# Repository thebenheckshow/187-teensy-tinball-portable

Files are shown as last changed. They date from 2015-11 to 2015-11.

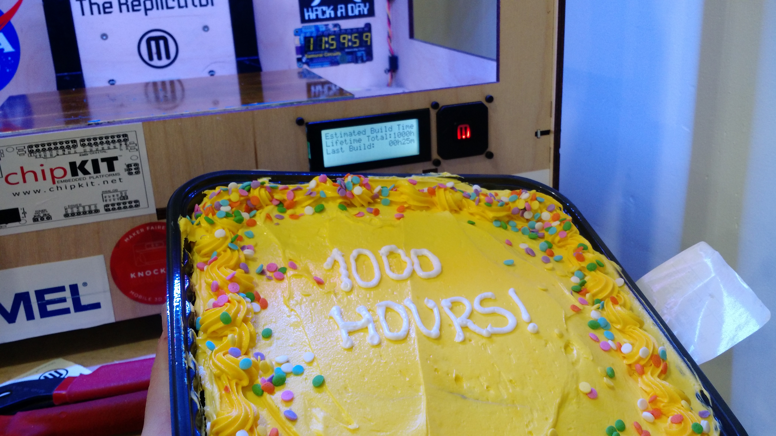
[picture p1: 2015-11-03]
pics/IMG_20150506_124653176.jpg

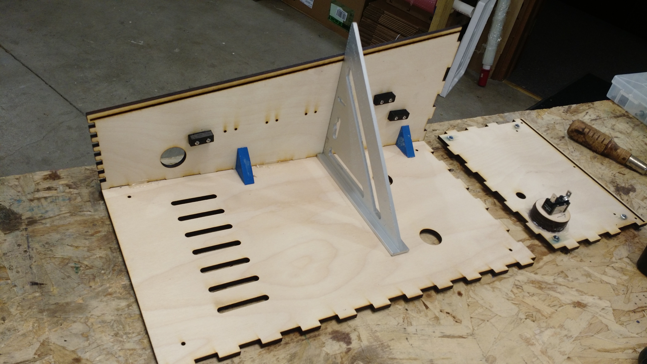
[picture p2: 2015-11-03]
pics/IMG_20150509_173802297.jpg

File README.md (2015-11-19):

# 187-teensy-tinball-portable

In this episode series Ben creates a mini pinball machine portable for this years Freescale Technology Forum in Austin,Texas. The pinball machine be half scale, will run off of the Teensy 3.1 and will have electronic music and scoring.

Visit the Ben Heck Community and Suggest a Build: http://www.element14.com/tbhs

Part 1: http://www.element14.com/community/docs/DOC-76788/l/episode-187-ben-heck-s-teensy-pinball-portable-part-1-episode

Part 2: http://www.element14.com/community/docs/DOC-77092/l/episode-189-ben-hecks-teensy-pinball-portable-part-2-episode

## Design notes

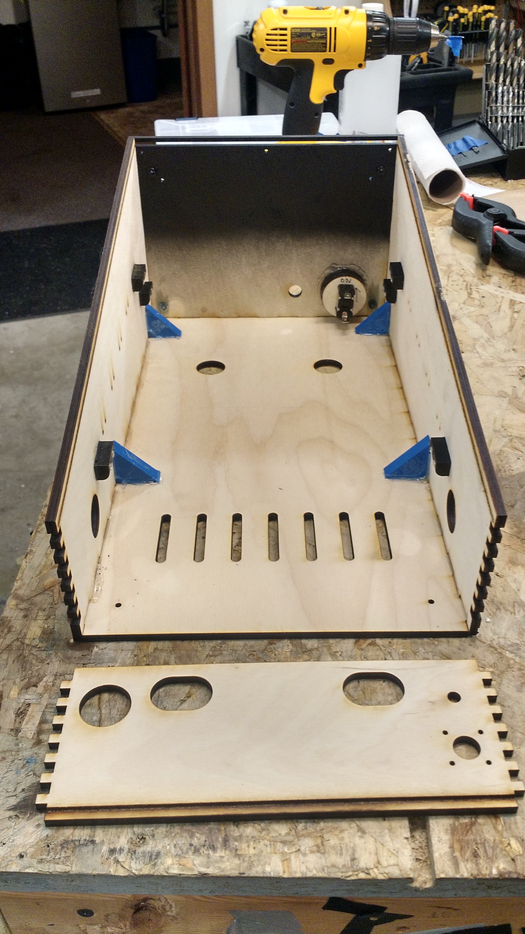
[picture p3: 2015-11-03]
pics/IMG_20150509_180624918_HDR.jpg

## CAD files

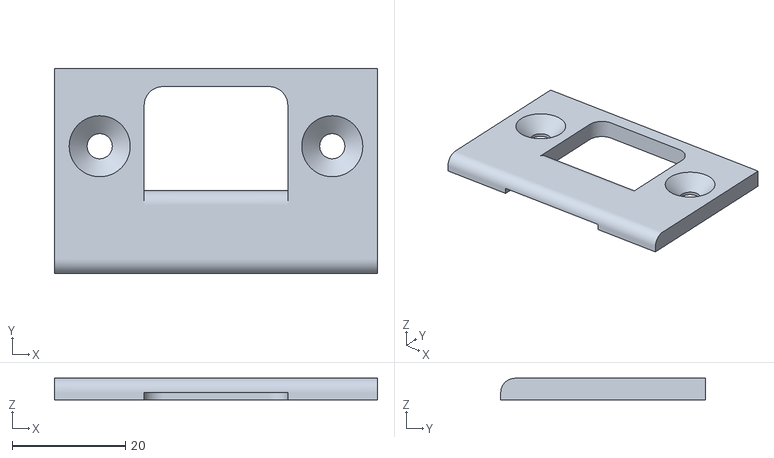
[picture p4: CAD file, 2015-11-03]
3D parts/STL/Door Fixer.stl
57.1 x 36.2 x 3.81

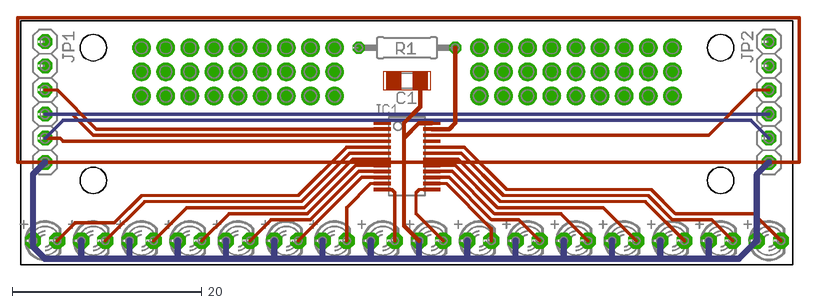
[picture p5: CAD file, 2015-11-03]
parts/LED Driver Boards/led_driver.dxf
82.5 x 26.2

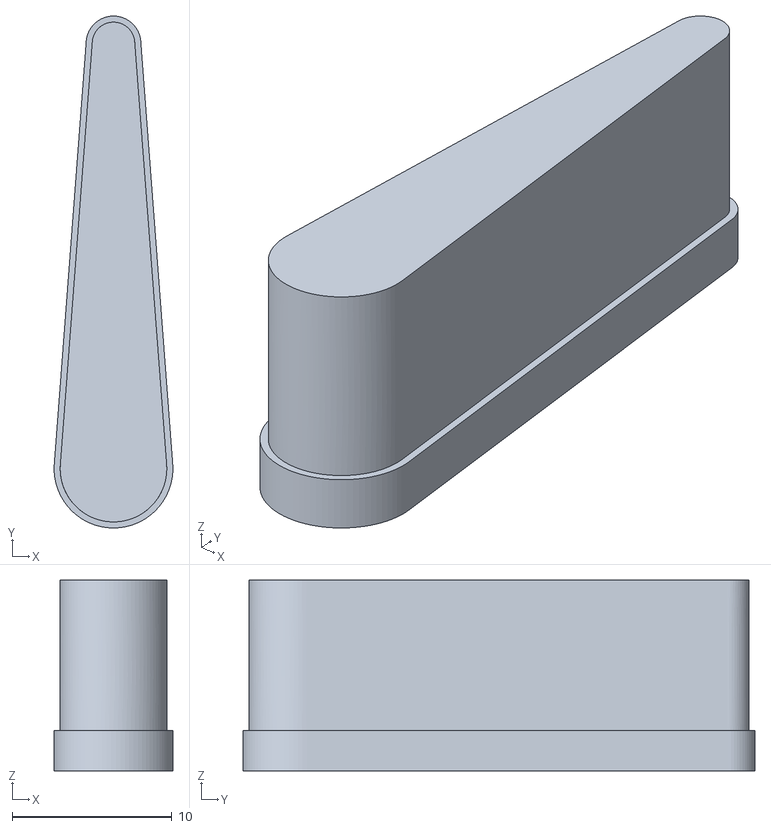
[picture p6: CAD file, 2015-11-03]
STL Test/flipper_shape.stl
7.43 x 32.0 x 11.9

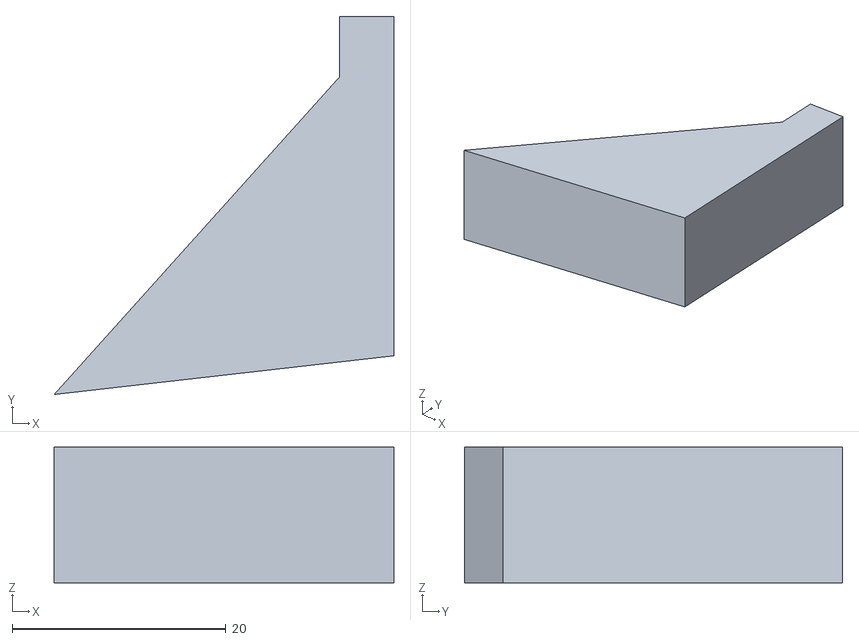
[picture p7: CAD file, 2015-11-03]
3D parts/STL/6 point 5 Triangle.stl
31.8 x 35.4 x 12.7

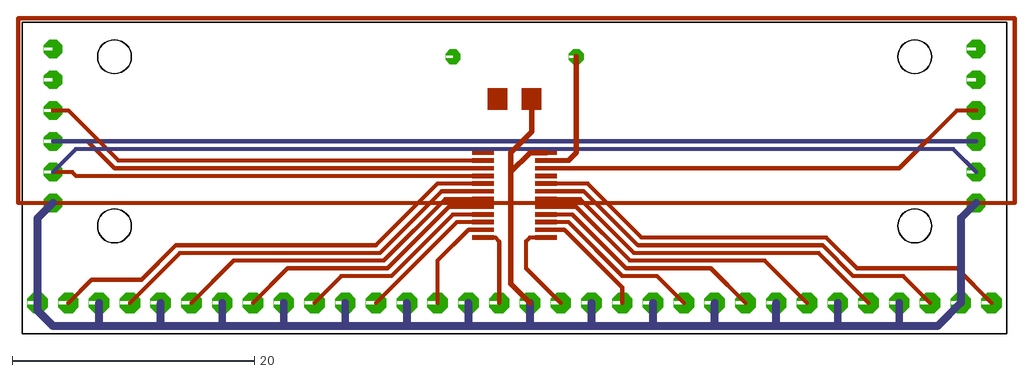
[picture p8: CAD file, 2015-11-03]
parts/LED Driver Boards/led_driver2.dxf
82.5 x 26.2

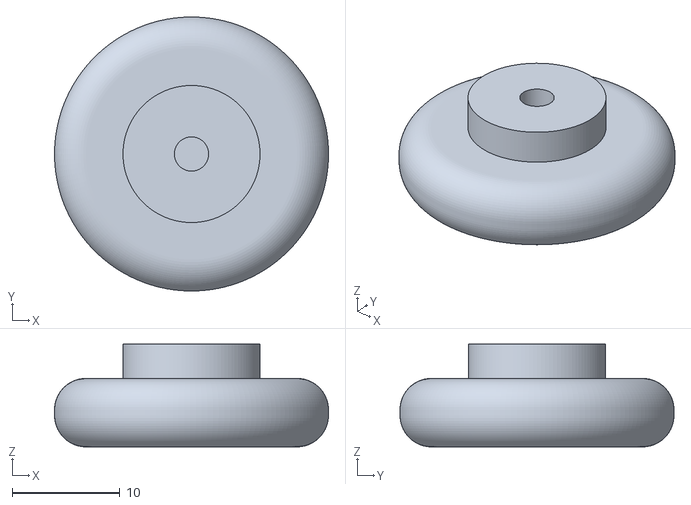
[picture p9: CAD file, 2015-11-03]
3D parts/STL/Plunger Handle.stl
25.4 x 25.4 x 9.53

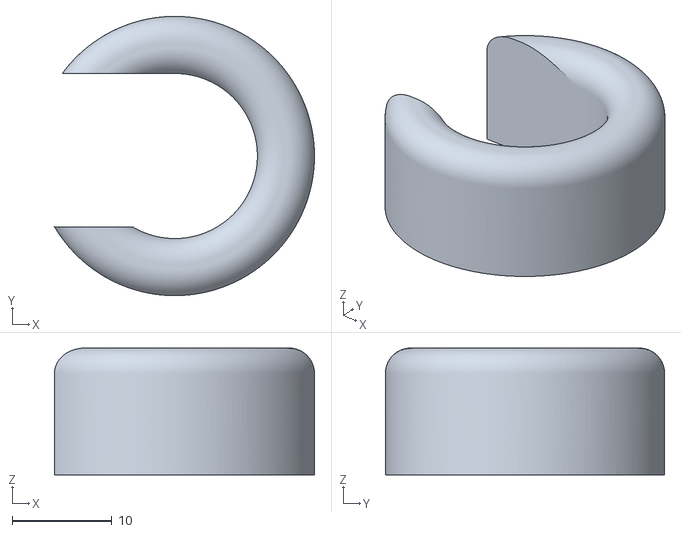
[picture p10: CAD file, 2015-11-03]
3D parts/STL/Left Ramp End.stl
26.0 x 27.9 x 12.7

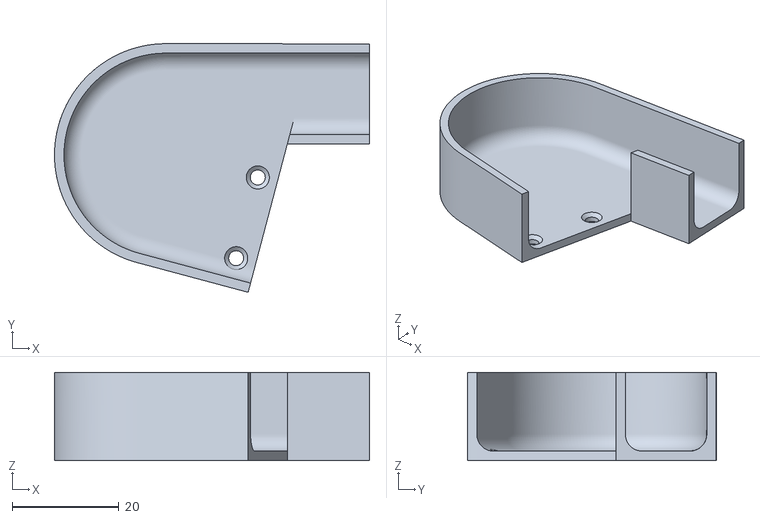
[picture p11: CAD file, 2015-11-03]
3D parts/STL/Right Ramp Loop 2.stl
58.9 x 46.5 x 16.5

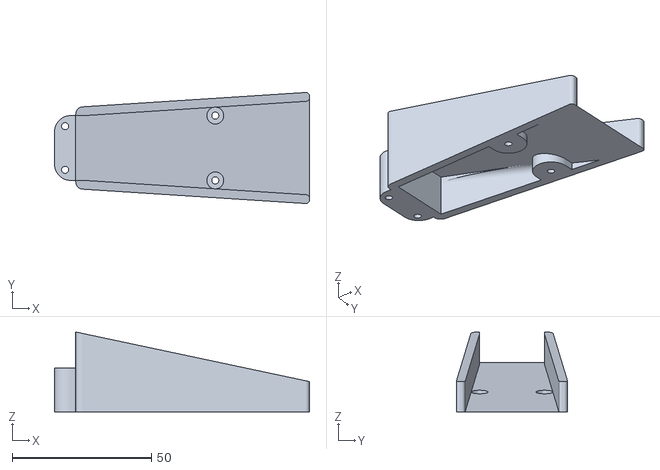
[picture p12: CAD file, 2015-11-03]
3D parts/STL/ramp.stl
91.4 x 39.8 x 28.7

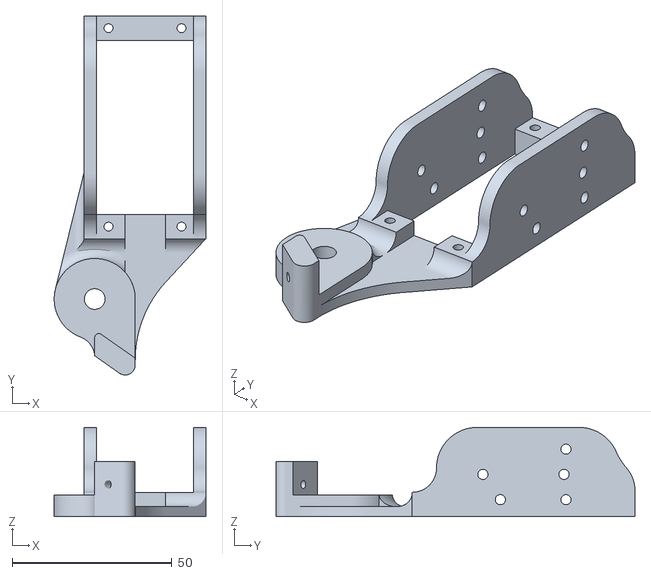
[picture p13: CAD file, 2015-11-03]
3D parts/STL/New Flipper Frame.stl
47.5 x 112.5 x 27.9

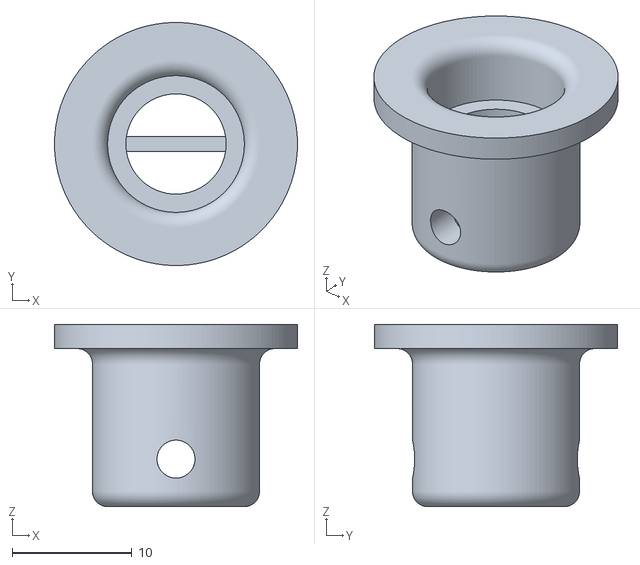
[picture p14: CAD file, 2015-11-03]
3D parts/STL/Stopper Cap.stl
20.3 x 20.3 x 15.2

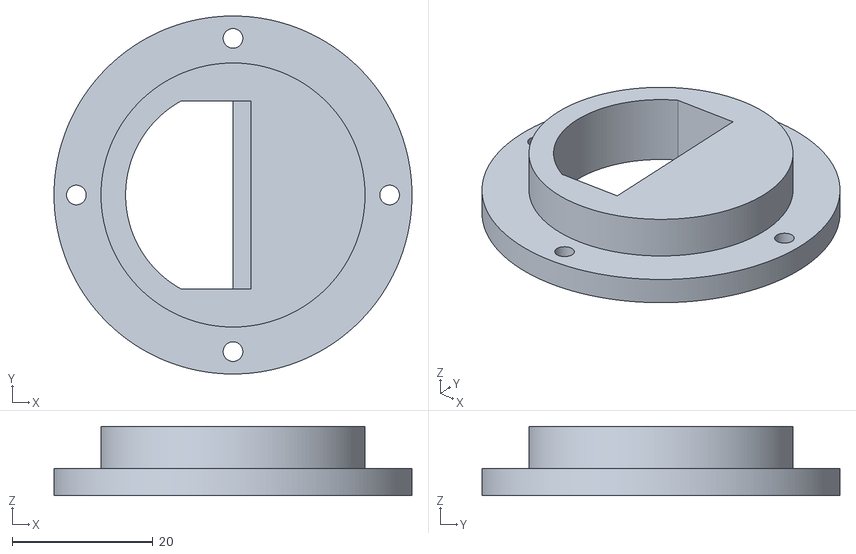
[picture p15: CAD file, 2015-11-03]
3D parts/STL/Target Base.stl
50.8 x 50.8 x 9.81

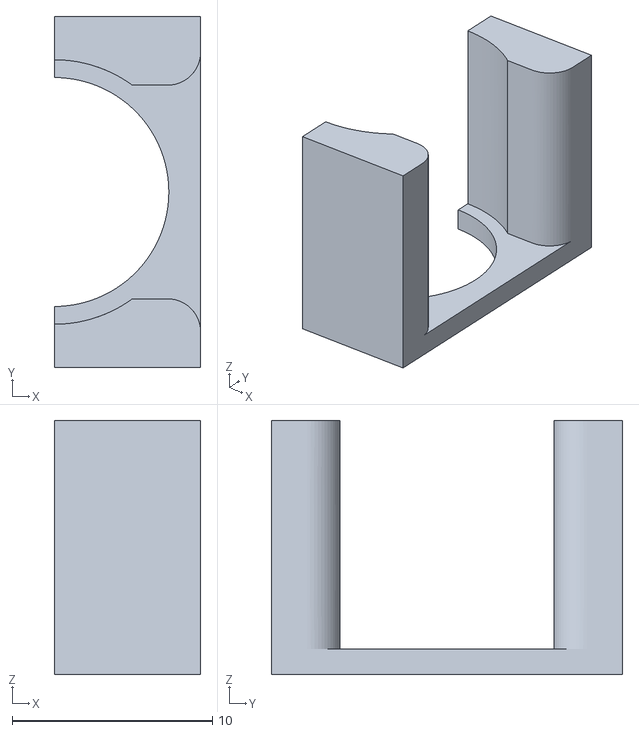
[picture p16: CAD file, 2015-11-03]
3D parts/STL/Ball Launch Holder.stl
7.30 x 17.5 x 12.7

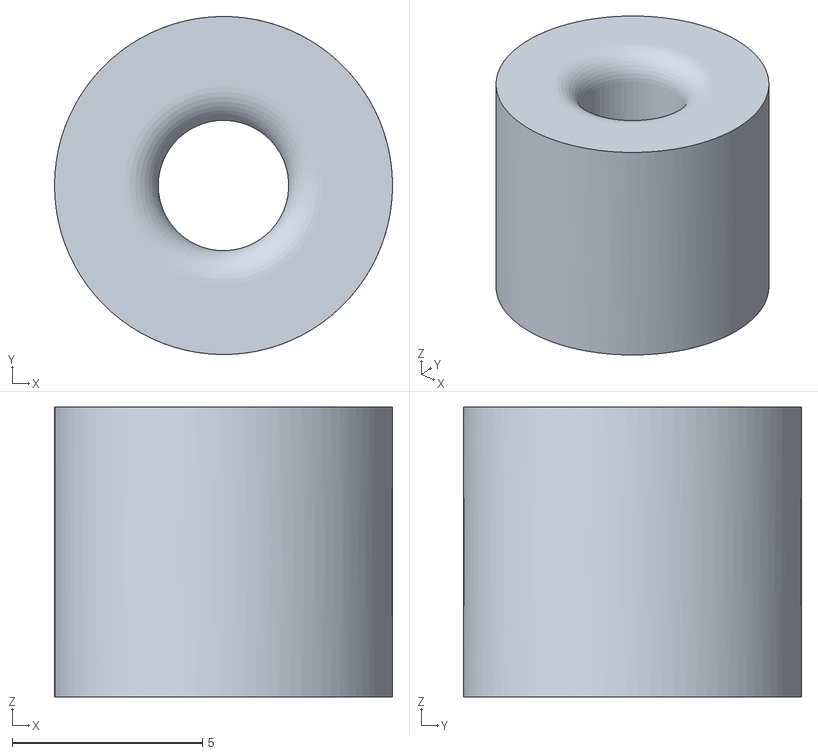
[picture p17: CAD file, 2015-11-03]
3D parts/STL/Spacer point 3.stl
8.89 x 8.89 x 7.62

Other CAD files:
3D parts/STL/Drop Target.stl
3D parts/STL/Opto Mount 2.stl
3D parts/STL/Shooter Tip.stl
3D parts/STL/Large LED holder.stl
3D parts/STL/Flipper Bat.stl
3D parts/STL/Foot.stl
3D parts/STL/Habitrail End 2.stl
3D parts/STL/Habitrail End.stl
3D parts/STL/Habitrail Top.stl
3D parts/STL/Hole Temp.stl
3D parts/STL/Knob.stl
3D parts/STL/LED holder.stl
3D parts/STL/LED screw left.stl
3D parts/STL/LED screw right.stl
3D parts/STL/Launch Ramp.stl
3D parts/STL/Left Ramp Loop.stl
3D parts/STL/New Flipper Clamp Flipped.stl
3D parts/STL/New Flipper Clamp.stl
3D parts/STL/New Flipper Frame Flipped.stl
3D parts/STL/New Flipper Linkage.stl
3D parts/STL/Opto Mount.stl
3D parts/STL/Plastic Spacer 200 mils THEEEN.stl
3D parts/STL/Plastic Spacer 200 mils.stl
3D parts/STL/Right Ramp End.stl
3D parts/STL/Right Ramp Loop.stl
3D parts/STL/Shooter Rod Mount 2.stl
3D parts/STL/Shooter Rod Mount.stl
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

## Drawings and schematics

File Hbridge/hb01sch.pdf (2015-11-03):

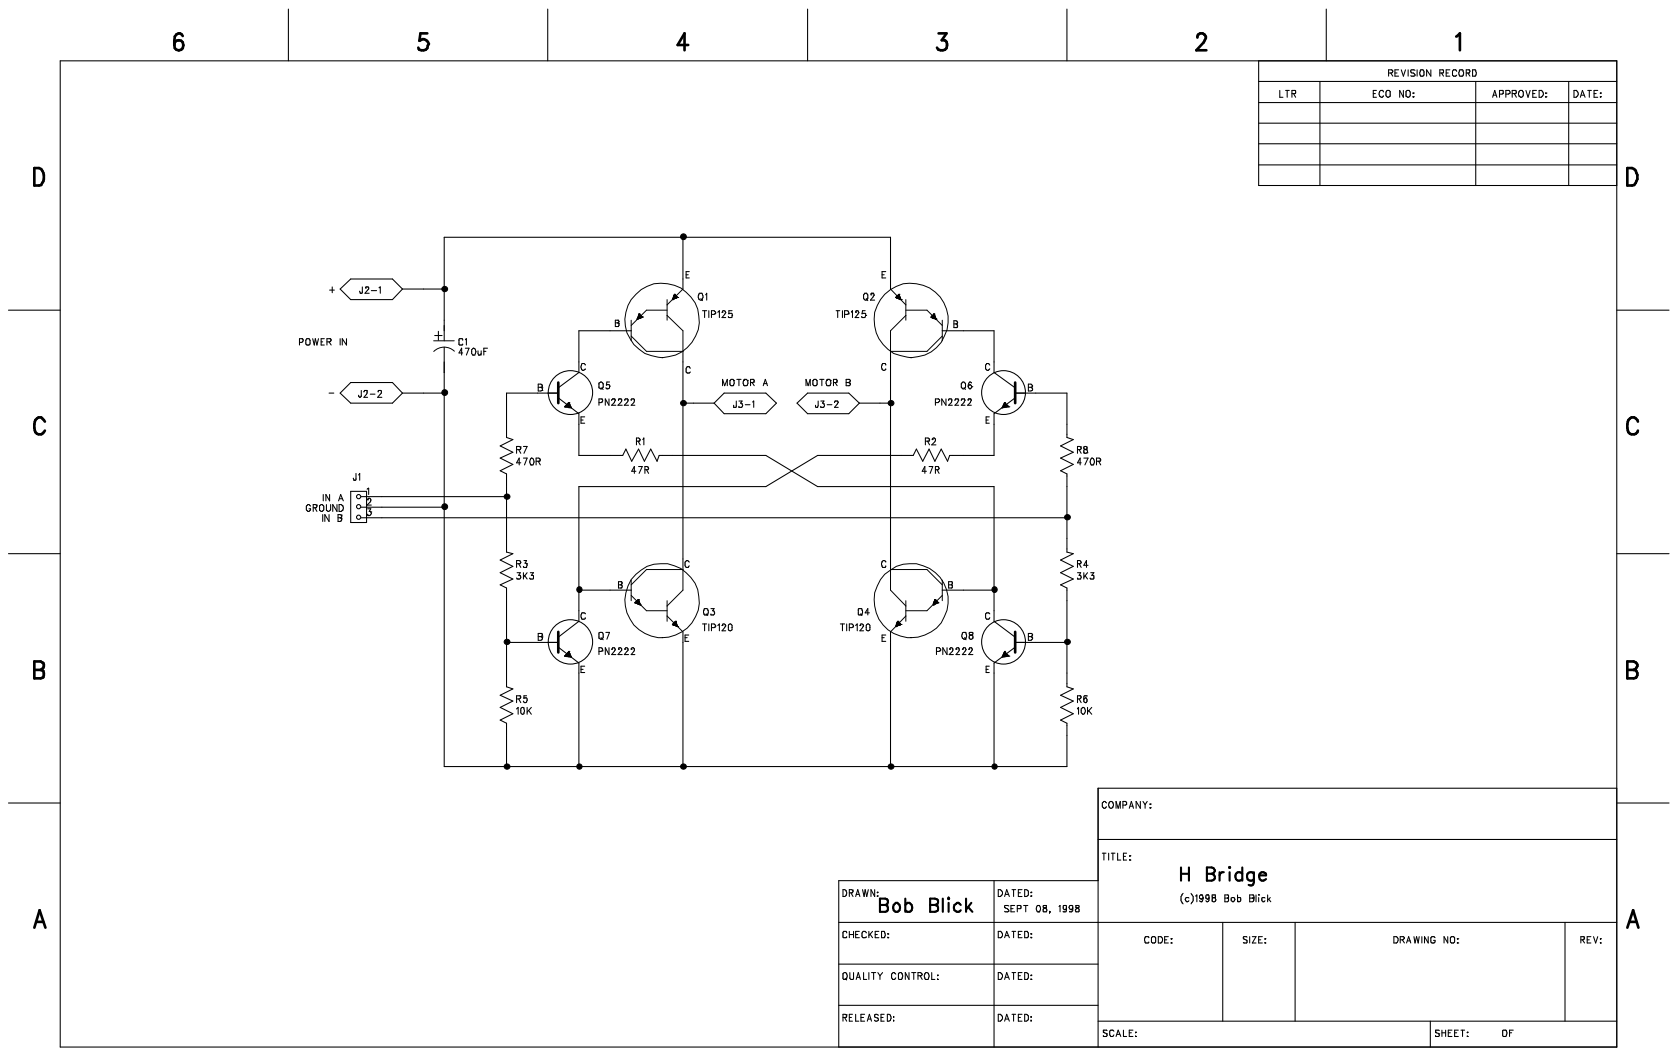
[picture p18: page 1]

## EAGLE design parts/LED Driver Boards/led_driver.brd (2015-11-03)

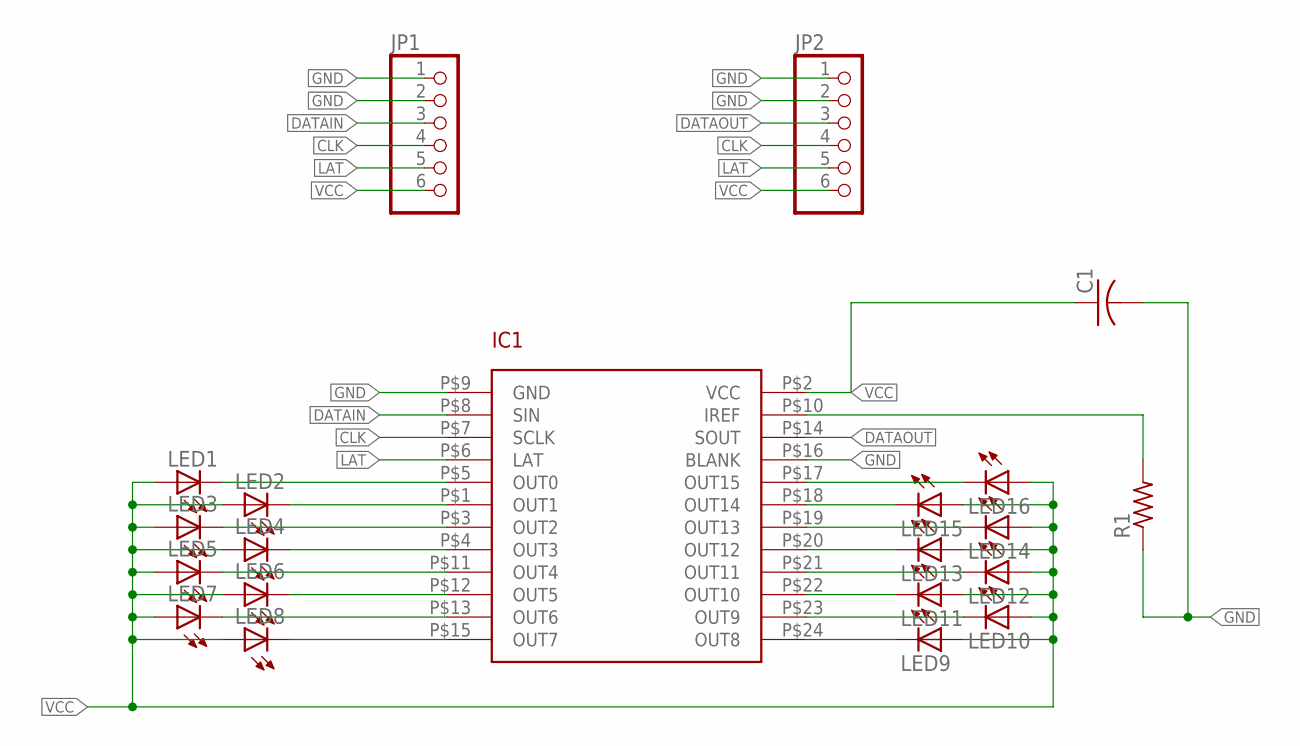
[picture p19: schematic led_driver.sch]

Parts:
C1: C-USC1206; C1206
IC1: TLC59282; SSOP-24
JP1, JP2: PINHD-1X6; 1X06
LED1, LED2, LED3, LED4, LED5, LED6, LED7, LED8, LED9, LED10, LED11, LED12, LED13, LED14, LED15, LED16: LED3MM
R1: R-US_0207/10; 0207/10

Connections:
CLK: IC1.P$7 (SCLK), JP1.4, JP2.4
DATAIN: IC1.P$8 (SIN), JP1.3
DATAOUT: IC1.P$14 (SOUT), JP2.3
GND: C1.2, IC1.P$9 (GND), IC1.P$16 (BLANK), JP1.1, JP1.2, JP2.1, JP2.2, R1.1
LAT: IC1.P$6 (LAT), JP1.5, JP2.5
unnamed: IC1.P$5 (OUT0), LED1.K (C)
unnamed: IC1.P$1 (OUT1), LED2.K (C)
unnamed: IC1.P$3 (OUT2), LED3.K (C)
unnamed: IC1.P$4 (OUT3), LED4.K (C)
unnamed: IC1.P$11 (OUT4), LED5.K (C)
unnamed: IC1.P$12 (OUT5), LED6.K (C)
unnamed: IC1.P$13 (OUT6), LED7.K (C)
unnamed: IC1.P$15 (OUT7), LED8.K (C)
unnamed: IC1.P$17 (OUT15), LED16.K (C)
unnamed: IC1.P$18 (OUT14), LED15.K (C)
unnamed: IC1.P$19 (OUT13), LED14.K (C)
unnamed: IC1.P$20 (OUT12), LED13.K (C)
unnamed: IC1.P$21 (OUT11), LED12.K (C)
unnamed: IC1.P$22 (OUT10), LED11.K (C)
unnamed: IC1.P$23 (OUT9), LED10.K (C)
unnamed: IC1.P$24 (OUT8), LED9.K (C)
unnamed: IC1.P$10 (IREF), R1.2
VCC: C1.1, IC1.P$2 (VCC), JP1.6, JP2.6, LED1.A, LED2.A, LED3.A, LED4.A, LED5.A, LED6.A, LED7.A, LED8.A, LED9.A, LED10.A, LED11.A, LED12.A, LED13.A, LED14.A, LED15.A, LED16.A

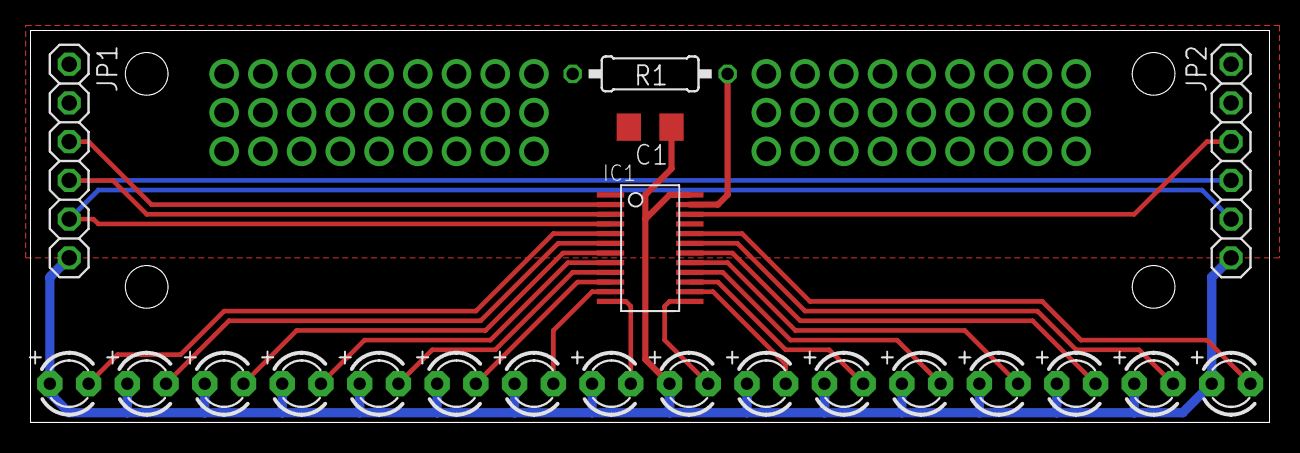
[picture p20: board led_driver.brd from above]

Board: 4 copper layers, 81.3 x 25.7 mm, 21 parts (0 on the bottom side), 23 nets.

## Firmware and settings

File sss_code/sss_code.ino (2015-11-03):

#include "pinball.h"
#include "kinetis.h"
#include "pins_arduino.h"
#include <EEPROM.h>

#include <Audio.h>
#include <Wire.h>
#include <SPI.h>
#include <SD.h>

volatile byte lamp[32];
volatile byte solenoid[16];
volatile unsigned short LEDcommand = 0;
volatile unsigned char whichDigit = 0;												//Which digit we're sending to the MAX7221
volatile char scoreString[7] = {0, 0, 0, 0, 0, 0, 0};								//Used to build the digits to go on the LED
volatile char tempString[7] = {0, 0, 0, 0, 0, 0, 0};								//Used to make temp Score String to right-align value
volatile unsigned short digitData = 0;												//Used to build data going to the MAX7221	
volatile unsigned short cabTemp = 0;												//Used to collect the cabinet switch data
byte LEDglow = 0;
byte LEDglowDir = 0;

unsigned long currentMillis = 0;
char sfxFilename[8] = {'x', 'x', 'x', '.', 'W', 'A', 'V', 0};
byte priority[2];
byte musicPlaying = 0;
char currentMusic[3] = {'x', 'x', 'x'};

int timerX = 0;

AudioPlaySdWav           playWav[2];					//Set up two channel stereo audio mixed into a stereo signal
AudioMixer4              mixer2;
AudioMixer4              mixer1;
AudioOutputI2S           i2s1;
AudioConnection          patchCord1(playWav[0], 0, mixer1, 0);
AudioConnection          patchCord2(playWav[0], 1, mixer2, 0);
AudioConnection          patchCord3(playWav[1], 0, mixer1, 1);
AudioConnection          patchCord4(playWav[1], 1, mixer2, 1);
AudioConnection          patchCord5(mixer2, 0, i2s1, 1);
AudioConnection          patchCord6(mixer1, 0, i2s1, 0);
AudioControlSGTL5000     sgtl5000_1;

IntervalTimer pollIOtimer;								//Set up a timer

void setup() {                

    Serial.begin(9600);
	
	pinMode(shiftClock, OUTPUT);						//Master clock  
	pinMode(shiftLatch, OUTPUT); 						//Master latch
	pinMode(shiftLamp0, OUTPUT); 						//LED driver 0 (lamps 0-15)
	pinMode(shiftLamp1, OUTPUT); 						//LED driver 1(lamps 16-31)
	pinMode(shiftSol, OUTPUT); 							//Solenoid drivers 0-15
	pinMode(shiftLED, OUTPUT); 							//MAX7221 7 segment LED driver
	pinMode(shiftInput, INPUT);							//Shift register switch input line
	
	pollIOtimer.begin(pollIO, 4000);					//Do the PollIO routine 250Hz (or every 4000 microseconds)

	AudioMemory(32);									//Twice of the max, which seems to be 6

	sgtl5000_1.enable();
	sgtl5000_1.volume(1);

	SPI.setMOSI(7);
	SPI.setSCK(14);
	
	if (!(SD.begin(10))) {	
		while (1) {
		  Serial.println("Unable to access the SD card");	// stop here, but print a message repetitively 
		  delay(500);
		}
	}
	else {
		Serial.println("Connected to SD card!");
		delay(500);      
	}


	resetLED();											//Reset the display
	
}

void loop() {

	machineReset();

	while (run == 0) {
	
		Serial.println(cabinet, BIN);	
	
		//Attract Mode Shit
	
		if (cabinet & startButton) {

			if (cabinet & drain) {	//Ball must be in drain to start!
				startButtonTimer = 250;
				run = 1;											//Advance state if START pressed
			}
			else {
				scoreString[0] = digitMaker[17]; 	//N
				scoreString[1] = digitMaker[0];		//0	
				scoreString[2] = 0; 				//space	
				scoreString[3] = digitMaker[10]; 	//B
				scoreString[4] = digitMaker[11];	//A		
				scoreString[5] = digitMaker[12];	//L
				scoreString[6] = digitMaker[12];	//L	
				displayCycle = 0;					//So we'll see message
			}
		}

		displayCycle += 1;

		switch(displayCycle) {
			
			case 1500:
				blankLED();
				scoreString[0] = digitMaker[15]; 	//H
				scoreString[1] = digitMaker[1];		//1		
				scoreString[2] = digitMaker[16];	//G
				scoreString[3] = digitMaker[15];	//H
			break;
			case 3000:
				makeScore(highScore);	//Show score, and repeat	
				displayCycle = 0;
			break;		
		}
		
		houseKeeping();
	
	}

	startGame();
	
	while (ball < 4) {
	
		gameLoop();
	}
	
	gameOver();
	
}

void gameLoop() {

	timers();
	
	switchCheck();
	
	houseKeeping();							//1 ms cycle lock and Music Loop check performed in this function

}

void timers() {

	if (motorState) {						//Motor is supposed to be doing something?
		doMotor();							//Go do it
	}
	
	if (leftLoopTimer) {		
		leftLoopTimer -= 1;	
	}	
	
	if (leftRampTimer) {		
		leftRampTimer -= 1;	
	}	
	
	if (rightRampTimer) {		
		rightRampTimer -= 1;	
	}
	
	if (rightLoopTimer) {		
		rightLoopTimer -= 1;	
	}	

	if (startButtonTimer and (cabinet & startButton) == 0) {	
		startButtonTimer -= 1;		
	}
	
	displayCycle += 1;

	switch(displayCycle) {
		
		case 2000:
		if (numPlayers > 1) {
			blankLED();
			scoreString[0] = digitMaker[13];		//P
			scoreString[1] = digitMaker[12];		//L	
			scoreString[2] = digitMaker[11];		//A				
			scoreString[3] = digitMaker[14];		//Y skip one space...
			scoreString[5] = digitMaker[player];	//Player #			
		}		
		else {
			displayCycle = 2999;		//If only 1 player, don't show player # just skip to score
		}
		break;
		case 3000:		
			blankLED();
			scoreString[1] = digitMaker[10]; 	//B
			scoreString[2] = digitMaker[11];	//A		
			scoreString[3] = digitMaker[12];	//L
			scoreString[4] = digitMaker[12];	//L skip one space then	
			scoreString[6] = digitMaker[ball];	//Ball #

		break;	
		case 4000:
			makeScore(playerScore[player]);	//Show score, and repeat	
			displayCycle = 1000;
		break;		
	}
	
}

void switchCheck() {

	//FLIPPERS GO HERE!

	flippers();
	
	if ((cabinet & startButton) == 1 and startButtonTimer == 0) {	
		startButtonTimer = 250;
		if (numPlayers < 4 and ball == 1) {						//Can only add players on Ball 1
			numPlayers += 1;			//Increment player #		
			playSFX(0, 'S', 'B', '0' + numPlayers, 255);		//Add player 2-4		
		}	
	}

	if ((cabinet & drain) and drainState == 0) {
	
		drainBall();
	
	}

	if ((cabinet & leftLoop) and leftLoopTimer == 0 and rightLoopTimer == 0) {
		leftLoopTimer = loopDebounce;
	
		if (mode == 0) {					//No mode?
		
			modePrompt(2);					//Play generic sound for orbits, with START MODE prompts
			
			leftOrbitCount[player] += 1;
			
			if (leftOrbitCount[player] > 3) {
				leftOrbitCount[player] = 0;
				addScore(2000);
			}
			else {
				addScore(1000);
			}
			
			playerLights();
	
		}
		else {								//Some mode is active...
		
			if (mode == 1) {				//Hubble mode? correct shot
			
				hubbleProgress[player] += 1;
				playSFX(0, 'A', 'A' + hubbleProgress[player], '1' + random(3), 255);	//Progress dialog

				if (hubbleProgress[player] == 3) {				
					addScore(50000);
					winMode();
				}
				else {
					addScore(5000);
				}
				playerLights();
				
			}
			else {
			
				modePrompt(2);				//Play generic sound for orbits, with MODE PROGRESS prompts
				addScore(2000);	
			}
			
		}

	}
	
	if ((cabinet & leftRamp) and leftRampTimer == 0) {
		leftRampTimer = rampDebounce;
				
		if (mode == 0) {					//No mode?
		
			modePrompt(1);					//Play generic sound for orbits, with START MODE prompts
			leftRampCount[player] += 1;
			
			if (leftRampCount[player] > 3) {
				leftRampCount[player] = 0;
				addScore(4000);
			}
			else {
				addScore(2000);
			}
			
			playerLights();
		}
		else {								//Some mode is active...
		
			if (mode == 2) {				//ISS mode? correct shot
			
				issProgress[player] += 1;
				playSFX(0, 'B', 'A' + issProgress[player], '1' + random(3), 255);	//Progress dialog

				if (issProgress[player] == 3) {				
					addScore(50000);
					winMode();
				}
				else {
					addScore(5000);
				}
				playerLights();	
				
			}
			else {
			
				modePrompt(1);				//Play generic sound for orbits, with MODE PROGRESS prompts
				addScore(2000);
			}
			
		}
	}
	
	if ((cabinet & targetDown) and targetState == 1 and motorState == 0) {	//Switch hit and target wasn't already hit?

		addScore(5000);
	
		light(15, 0);

		targetState = 0;							//Target down!
		
		startMode();
	}	

	if ((cabinet & rightRamp) and rightRampTimer == 0) {
	
		rightRampTimer = rampDebounce;
		
		if (mode == 0) {					//No mode?
		
			modePrompt(1);					//Play generic sound for orbits, with START MODE prompts
			rightRampCount[player] += 1;
			
			if (rightRampCount[player] > 3) {
				rightRampCount[player] = 0;
				addScore(4000);
			}
			else {
				addScore(2000);
			}
			
			playerLights();
		}
		else {								//Some mode is active...
		
			if (mode == 3) {				//Asteroid mode? correct shot
			
				asProgress[player] += 1;
				playSFX(0, 'C', 'A' + asProgress[player], '1' + random(3), 255);	//Progress dialog

				if (asProgress[player] == 3) {				
					addScore(50000);
					winMode();
				}
				else {
					addScore(5000);
				}
				playerLights();	
				
			}
			else {
			
				modePrompt(1);				//Play generic sound for orbits, with MODE PROGRESS prompts
				addScore(2000);
			}
			
		}
	
	}
	
	if ((cabinet & rightLoop) and leftLoopTimer == 0 and rightLoopTimer == 0) {
		rightLoopTimer = loopDebounce;
		
		if (mode == 0) {					//No mode?
		
			modePrompt(3);					//Play generic sound for orbits, with START MODE prompts
			rightOrbitCount[player] += 1;
			
			if (rightOrbitCount[player] > 3) {
				rightOrbitCount[player] = 0;
				addScore(2000);
			}
			else {
				addScore(1000);
			}
			
			playerLights();
		}
		else {								//Some mode is active...
		
			if (mode == 4) {				//Satellite mode? correct shot
			
				satProgress[player] += 1;
				playSFX(0, 'B', 'A' + satProgress[player], '1' + random(3), 255);	//Progress dialog

				if (satProgress[player] == 3) {				
					addScore(50000);
					winMode();
				}
				else {
					addScore(5000);
				}
				playerLights();	
				
			}
			else {
			
				modePrompt(3);				//Play generic sound for orbits, with MODE PROGRESS prompts
				addScore(1000);
			}
			
		}
		
	}	

	// if (cabinet & startButton) {	
	
		// Serial.print("Audio Mem Current: ");
		// Serial.print(AudioMemoryUsage());	
		// Serial.print(" Audio Mem Max: ");
		// Serial.println(AudioMemoryUsageMax());
		// delay(10);	
	// }	
	
	
}

void flippers() {								//Control flippers, if enabled, as well as ball launcher

	if ((cabinet & leftButton) and LFlipTime == -1) {		//Left button pressed?
		leftDebounce += 1;
		if (leftDebounce > flipperDebounce) {
			leftDebounce = flipperDebounce;
			solenoid[leftFlipper] = 1;							//Set flipper
			LFlipTime = FlipPower;
		}
	}

	if ((cabinet & rightButton) and RFlipTime == -1) {		//Right button pressed?
		rightDebounce += 1;
		if (rightDebounce > flipperDebounce) {
			rightDebounce = flipperDebounce;
			solenoid[rightFlipper] = 1;							//Set flipper
			RFlipTime = FlipPower;
		}
	}

	//Flippers can time out or be released even if not enabled. (which is why Flipper routine should ALWAYS run)

	if (LFlipTime < -1) {	
		LFlipTime += 1;	
	}
	
	if (LFlipTime > 0) {
		LFlipTime -= 1;
		if (LFlipTime == 0) { 					//Did timer run out OR EOS hit?
			solenoid[leftFlipper] = 0;							//Turn off flipper
			LholdTime = holdTop + 5;			 //Set PWM timer
		}
	}

	if (LholdTime) {
	
		if (LholdTime == holdTop) {
			solenoid[leftFlipper] = 1;							//Turn on flipper
		}
		if (LholdTime == holdHalf) {
			solenoid[leftFlipper] = 0;							//Turn off flipper
		}
		if (LholdTime == 1) {									//Almost done?
			LholdTime = holdTop + 1;							//Reset it
		}
		LholdTime -= 1;
	}
	
	if ((cabinet & leftButton) == 0) { //Button released? (normal state)
		leftDebounce = 0;
		LFlipTime = -10;				//Make flipper re-triggerable, with debounce
		LholdTime = 0;				//Disable hold timer.
		solenoid[leftFlipper] = 0;							//Turn off flipper	
	}

	if (RFlipTime < -1) {	
		RFlipTime += 1;	
	}
	
	if (RFlipTime > 0) {
		RFlipTime -= 1;
		if (RFlipTime == 0) { //Did timer run out OR EOS hit?
			solenoid[rightFlipper] = 0;							//Turn off flipper
			RholdTime = holdTop + 5;			 //Set PWM timer
			//digitalWrite(RFlipLow, 1); //Switch on hold current
		}
	}

	if (RholdTime) {
	
		if (RholdTime == holdTop) {
			solenoid[rightFlipper] = 1;							//Turn on flipper
		}
		if (RholdTime == holdHalf) {
			solenoid[rightFlipper] = 0;							//Turn off flipper
		}
		if (RholdTime == 1) {			//Almost done?
			RholdTime = holdTop + 1;		//Reset it
		}
		RholdTime -= 1;
	}
			
	if ((cabinet & rightButton) == 0) { 						//Button released? (normal state)
		rightDebounce = 0;
		RFlipTime = -10;										//Make flipper re-triggerable, with debounce
		RholdTime = 0;											//Disable hold timer
		solenoid[rightFlipper] = 0;							//Turn off flipper	
	}

}

void drainBall() {

	solenoid[leftFlipper] = 0;							//Turn off flipper
	solenoid[rightFlipper] = 0;							//Turn off flipper	

	playSFX(0, 'D', 'R', '1' + random(5), 255);			//Abort abort!

	allLight(0);

	modeMiss = 0;

	resetLED();											//Reset the display
	
	for (int x = 0 ; x < 7 ; x++) {
		scoreString[x] = 1;			//Make all dashes
	}
	
	resetTarget();
	
	player += 1;
	
	if (player > numPlayers) {
		player = 1;
		ball += 1;
	}
	
	if (ball == 4) {
		return;
	}

	displayCycle = 1998;			//To show PLAY # (or BALL # in 1 player) right away
	
	int musicChange = 0;
	
	if (mode) {						//Check now so when we turn lights back on mode is correct
		musicChange = 1;
		mode = 0;
	}	
	
	delay(2000);					//Gives speech time to finish
	playerLights();		
	loadBall();
	
	if (musicChange) {
		playSFX(1, 'M', 'A', '3', 255);				//Normal music	
	}
	
	if (numPlayers > 1) {
		playSFX(0, 'S', 'P', '0' + player, 255);	//If more than 1 player, say which player is up
	}
	

}

void startGame() {

	resetLED();

	allLight(0);

	player = 1;
	mode = 0;								//Shots score points / make noise, no progress
	ball = 1;
	
	for (int x = 1 ; x < 5 ; x++) {
	
		playerScore[x] = 0;
		hubbleProgress[x] = 0;					//Mode 1
		issProgress[x] = 0;						//Mode 2
		asProgress[x] = 0;						//Mode 3
		satProgress[x] = 0;						//Mode 4

		leftOrbitCount[x] = 0;						//What to show in Mode 0
		leftRampCount[x] = 0;
		rightRampCount[x] = 0;
		rightOrbitCount[x] = 0;
		
	}

	makeScore(playerScore[player]);
	
	playSFX(1, 'M', 'A', '3', 255);
	playSFX(0, 'S', 'A', '1' + random(5), 255);			//Welcome to Space Shuttle!

	loadBall();
	//solenoid[flipperGo] = 1;
	resetTarget();
	
	//DO LIGHTS STARTING STATE PER PLAYER

	numPlayers = 1;
	
	playerLights();
	
}

void gameOver() {

	solenoid[leftFlipper] = 0;							//Turn off flipper
	solenoid[rightFlipper] = 0;							//Turn off flipper	

	stopMusic();

	blankLED();
	
	for (int x = 1 ; x < (numPlayers + 1) ; x++) {									//See if any players got a high score!
	
		if (playerScore[x] > highScore) {				//Did this player exceed high score?
			
			//NEW HIGH SCORE PLAYER X VOICE PROMPT!
			
			highScore = playerScore[x];					//Set the new high score...
			eepromLongWrite(1, highScore);				//and store to EEPROM
						
		}
		
	}

}

int loadBall() {

	if ((cabinet & drain) == 0) {				//No ball?
	
		return 0;								//Do not attempt load
	
	}

	solenoid[gateCoil] = 1;
	delay(250);	
	solenoid[loadCoil] = 1;		
	delay(500);
	solenoid[loadCoil] = 0;
	solenoid[gateCoil] = 0;	

	return 1;									//Success! (we hope)
	
}

void machineReset() {

	allLight(0);

	if ((cabinet & drain) == 0) {
		solenoid[gateCoil] = 1;
		delay(500);
		solenoid[gateCoil] = 0;		
	}
		
	for (int x = 0 ; x < 16 ; x++) {
	
		solenoid[x] = 0;
	
	}
	
	while ((cabinet & lowerLimit) == 0) {
	
		delay(1);
		solenoid[motorUp] = 0;
		solenoid[motorDown] = 1;
	
	}

	solenoid[motorDown] = 0;
	
	strobe(26, 2);
	strobe(24, 2);
	strobe(1, 3);
	strobe(4, 3);
	strobe(7, 3);
	strobe(10, 3);
	
	blink(28);
	blink(29);
	blink(30);
	blink(31);

	run = 0;
	
	if ((cabinet & startButton) and player == 0) {	//Hold START on boot to clear high score
		highScore = 1000;
		eepromLongWrite(1, highScore);	
	}
	else {
		highScore = eepromLongRead(1);		//Get the high score!	
	}
	
	displayCycle = 1499;
	
}

void playerLights() {

	allLight(0);
	
	if (mode == 0) {	
		blink(15);	
		
		light(26, 1);
		light(27, 1);
		light(24, 1);
		light(25, 1);
		
		strobe(28, 4);			

		switch(leftOrbitCount[player]) {
		
			case 0:		
				light(1, 0);
				light(2, 0);
				light(3, 0);

			break;
			case 1:
				light(1, 0);
				light(2, 0);	
				light(3, 1);		
			break;
			case 2:
				light(1, 0);
				light(2, 1);
				light(3, 1);		
			break;		
			case 3:		
				light(1, 1);
				light(2, 1);
				light(3, 1);			
			break;				
		}
		switch(leftRampCount[player]) {
		
			case 0:		
				light(4, 0);
				light(5, 0);
				light(6, 0);			
			break;
			case 1:
				light(4, 0);
				light(5, 0);
				light(6, 1);		
			break;
			case 2:
				light(4, 0);
				light(5, 1);
				light(6, 1);		
			break;		
			case 3:
				light(4, 1);
				light(5, 1);
				light(6, 1);		
			break;	
			
		}	
		switch(rightRampCount[player]) {
		
			case 0:		
				light(7, 0);
				light(8, 0);
				light(9, 0);			
			break;
			case 1:
				light(7, 0);
				light(8, 0);
				light(9, 1);		
			break;
			case 2:
				light(7, 0);
				light(8, 1);
				light(9, 1);		
			break;		
			case 3:		
				light(7, 1);
				light(8, 1);
				light(9, 1);		
			break;				
		}
		switch(rightOrbitCount[player]) {
		
			case 0:		
				light(10, 0);
				light(11, 0);
				light(12, 0);	
			break;
			case 1:
				light(10, 0);
				light(11, 0);
				light(12, 1);		
			break;
			case 2:
				light(10, 0);
				light(11, 1);
				light(12, 1);		
			break;		
			case 3:		
				light(10, 1);
				light(11, 1);
				light(12, 1);		
			break;				
		}	

	}
	else {
		light(15, 0);
		
		strobe(26, 2);
		strobe(24, 2);
		
		blink(28);
		blink(29);
		blink(30);
		blink(31);

		switch(hubbleProgress[player]) {
		
			case 0:		
				light(1, 0);
				light(2, 0);
				if (mode == 1) {
					blink(3);
				}
				else {
					light(3, 0);
				}	
			break;
			case 1:
				light(1, 0);
				if (mode == 1) {
					blink(2);
				}
				else {
					light(2, 0);
				}	
				light(3, 1);		
			break;
			case 2:
				if (mode == 1) {
					blink(1);
				}
				else {
					light(1, 0);
				}	
				light(2, 1);
				light(3, 1);		
			break;		
			case 100:		
				light(1, 1);
				light(2, 1);
				light(3, 1);
			
			break;				
		}
		switch(issProgress[player]) {
		
			case 0:		
				light(4, 0);
				light(5, 0);
				if (mode == 2) {
					blink(6);
				}
				else {
					light(6, 0);
				}	
			
			break;
			case 1:
				light(4, 0);
				if (mode == 2) {
					blink(5);
				}
				else {
					light(5, 0);
				}	
				light(6, 1);		
			break;
			case 2:
				if (mode == 2) {
					blink(4);
				}
				else {
					light(4, 0);
				}	
				light(5, 1);
				light(6, 1);		
			break;		
			case 100:
				light(4, 1);
				light(5, 1);
				light(6, 1);		
			break;				
		}	
		switch(asProgress[player]) {
		
			case 0:		
				light(7, 0);
				light(8, 0);
				if (mode == 3) {
					blink(9);
				}
				else {
					light(9, 0);
				}			
			break;
			case 1:
				light(7, 0);
				if (mode == 3) {
					blink(8);
				}
				else {
					light(8, 0);
				}	
				light(9, 1);		
			break;
			case 2:
				if (mode == 3) {
					blink(7);
				}
				else {
					light(7, 0);
				}	
				light(8, 1);
				light(9, 1);		
			break;		
			case 100:		
				light(7, 1);
				light(8, 1);
				light(9, 1);		
			break;				
		}
		switch(satProgress[player]) {
		
			case 0:		
				light(10, 0);
				light(11, 0);
				if (mode == 4) {
					blink(12);
				}
				else {
					light(12, 0);
				}			
			break;
			case 1:
				light(10, 0);
				if (mode == 4) {
					blink(11);
				}
				else {
					light(11, 0);
				}	
				light(12, 1);		
			break;
			case 2:
				if (mode == 4) {
					blink(10);
				}
				else {
					light(10, 0);
				}	
				light(11, 1);
				light(12, 1);		
			break;		
			case 100:		
				light(10, 1);
				light(11, 1);
				light(12, 1);		
			break;				
		}	
		
	}
	

}


void modePrompt(unsigned char whichSound) {

	modeMiss += 1;
	
	if (modeMiss == 3) {		//Every third "missed" shot do a prompt
	
		modeMiss = 0;
		
		if (mode == 0) {
			playSFX(0, 'P', 'E', '1' + random(5), 255);						//Shoot target to start modes!
		}
		else {
			playSFX(0, 'P', '@' + mode, '1' + random(5), 255);	//Shoot WHATEVER to advance mode
		}		
	}
	else {
		playSFX(0, 'S', 'X', '0' + whichSound, 250);		//Generic sounds (lower priority than prompts)
	}

}

void startMode() {

	mode = 0;		//Starting state

	if (hubbleProgress[player] == 100 and issProgress[player] == 100 and asProgress[player] == 100 and satProgress[player] == 100) {
	
		//Did them all? Start over.
		hubbleProgress[player] = 0;
		issProgress[player] = 0;
		asProgress[player] = 0;
		satProgress[player] = 0;
	
	}
	
	while (mode == 0) {		//Don't leave until we pick something
	
		mode = random(4) + 1;		//Pick a mode from 1-4
		
		switch(mode) {				//If randomly selected mode has been completed, pick another
		
			case 1:
				if (hubbleProgress[player] == 100) {
					mode = 0;
				}
				else {
					playSFX(0, 'A', 'A', '1' + random(3), 255);	//Fix hubble!
				}
			break;
			case 2:
				if (issProgress[player] == 100) {
					mode = 0;
				}
				else {
					playSFX(0, 'B', 'A', '1' + random(3), 255);	//ISS!
				}				
			break;		
			case 3:
				if (asProgress[player] == 100) {
					mode = 0;
				}
				else {
					playSFX(0, 'C', 'A', '1' + random(3), 255);	//Asteroid
				}					
			break;
			case 4:
				if (satProgress[player] == 100) {
					mode = 0;
				}
				else {
					playSFX(0, 'D', 'A', '1' + random(3), 255);	//Satellite
				}					
			break;			
		}
	
	}
	
	playSFX(1, 'M', 'B', '3', 255);				//Mission music


	playerLights();
	
}

void winMode() {

	switch(mode) {				//If randomly selected mode has been completed, pick another
	
		case 1:
			hubbleProgress[player] = 100;
		break;
		case 2:
			issProgress[player] = 100;
		break;		
		case 3:
			asProgress[player] = 100;
		break;
		case 4:
			satProgress[player] = 100;
		break;	
		
	}
	
	mode = 0;
	
	resetTarget();
	
	//CHECK IF ALL MODES WON

}
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

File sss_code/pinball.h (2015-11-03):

#define shiftClock	0
#define shiftLatch	1
#define shiftLamp0	2
#define shiftLamp1	3
#define	shiftSol	4
#define	shiftLED	5
#define shiftInput	31

#define strobeSpeed 100							//Number of millis before the strobe advances
#define blinkSpeed0 200							//Number of millis before the blink changes
#define blinkSpeed1 400							//Number of millis before the blink changes

								//0, 1,  2,  3,   4,  5,  6,  7,   8,   9,   b,	 A,   L,  P,   Y,  H,  G,  N
unsigned char digitMaker[18] = {126, 48, 109, 121, 51, 91, 95, 112, 127, 123, 31, 119, 14, 103, 39, 55, 94, 118};

int displayCycle = 0;								//Show score, then ball #, then player # (if more than 1 player)


unsigned char strobeAmount[32];
unsigned int strobePos[32];							//Which lamp the stobe is on (0 = target, 2 = third)
unsigned char lampState[32];						//What state each light is in 0 = standard, 1 = blink, 2 = strobe + 3, 4 = pulsate
unsigned int strobeTimer = 0;
unsigned char lightSpeed = 1;						//How fast blinks, pulsates and strobes occur. Depends on kernel speed too. Default = 1
unsigned int blinkTimer = 0;						//Timer for blinking the lights

unsigned short cabinet = 0;							//The last switch reading

unsigned long highScore = 0;						//What current high score is
unsigned long playerScore[5];						//Holds the score
unsigned char player = 0;							//Which player is active
unsigned char numPlayers = 0;      					//Total # of players in the game
int scoreMultiplier = 1;							//Default multiplier
unsigned char ball = 0;								//Which ball we're on
unsigned char drainState = 0;						//Keeps track if the ball is drained or not
unsigned char run = 0;								//What state the game is in

int saveTimer = 0;									//Save time per ball

//Mode variables

unsigned char mode = 0;								//Shots score points / make noise, no progress
unsigned char hubbleProgress[5];					//Mode 1
unsigned char issProgress[5];						//Mode 2
unsigned char asProgress[5];						//Mode 3
unsigned char satProgress[5];						//Mode 4

unsigned char leftOrbitCount[5];							//What to show in Mode 0
unsigned char leftRampCount[5];
unsigned char rightRampCount[5];
unsigned char rightOrbitCount[5];

unsigned char targetState = 1;						//What state the target is in. We check this at start of game / each ball
unsigned char modeMiss = 0;							//Miss X number of shots and it'll remind you what to do

int leftLoopTimer = 0;
int leftRampTimer = 0;
int rightRampTimer = 0;
int rightLoopTimer = 0;
int startButtonTimer = 0;

#define loopDebounce	1000
#define rampDebounce	1500

#define LEDbright	0x0A


//Inputs

#define leftRamp 1 << 15
#define rightRamp 1 << 14
#define leftLoop 1 << 13
#define rightLoop 1 << 12
#define drain 1 << 11

#define targetDown	1 << 8
#define lowerLimit	1 << 7
#define upperLimit	1 << 6

#define rightButton 1 << 2
#define leftButton	1 << 1
#define startButton 1



//Coils

#define leftCoil 	14
#define	rightCoil	15
#define loadCoil	13
#define gateCoil	12

#define rightFlipper 9
#define leftFlipper 8

#define flipperGo	8

#define motorDown	1
#define motorUp		0


int motorState = 0;



int LFlipTime = -1;							//Timer for flipper high current
int RFlipTime = -1;							//Timer for flipper high current

int LholdTime = 0;							//Timers for hold coil PWM
int RholdTime = 0;							//Timers for hold coil PWM

unsigned short FlipPower = 1; 						//Default flipper high power winding ON time, in cycles

int leftDebounce = 0;						//Flipper buttons don't use the built-in Cabinet Button Debounce
int rightDebounce = 0;						//These variables do it manually

#define flipperDebounce 5

#define holdTop			100 //250					//Used to PWM the hold coil on flippers
#define holdHalf		50 //125					//Save a calculation later	
